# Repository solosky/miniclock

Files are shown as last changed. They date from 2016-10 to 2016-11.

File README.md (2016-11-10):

# MINI CLOCK - 一个小巧漂亮的点阵时钟

标签（空格分隔）： 未分类

---

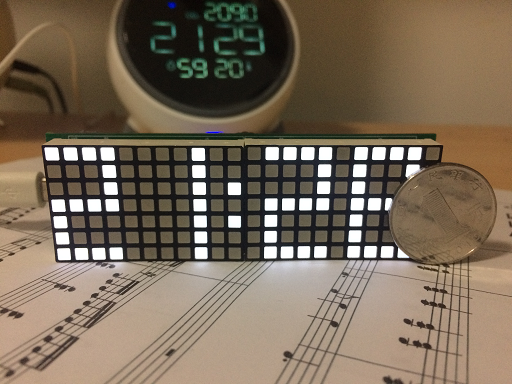
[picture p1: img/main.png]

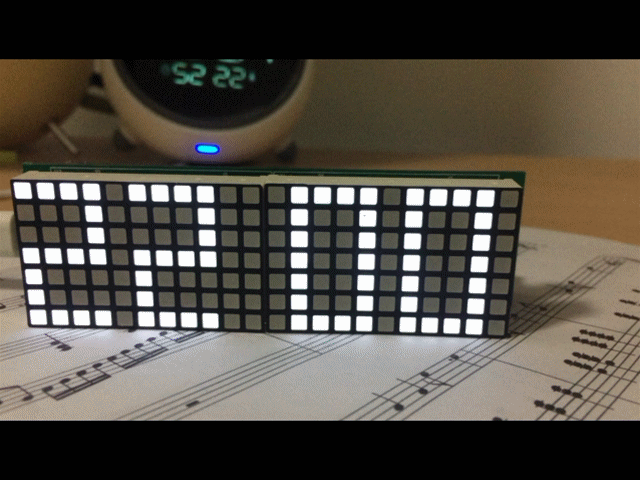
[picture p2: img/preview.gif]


# 特色

 1. 显示时间，日期，温度，湿度
 2. 时钟使用DS3231芯片，精度可以达一年误差30秒，无需校准
 3. 掉电仍走时，再次插电无需重新设置
 4. 支持DHT11/DHT22系列温湿度传感器，温度最高精度0.5℃
 5. 背光自动调节
 6. 支持两种经典字体
 7. 毫无特色的闹钟功能（待实现）
 8. MicroUSB电源接口，可以插USB提供电源
 9. 基于arduino，开放源代码，可以个性化定制

# 更新说明
 v1.1
 
 - 增加亮度调节功能，解决光敏电阻误差大的问题
 
v1.0

 - 第一个版本发布

# 缘起

之前我家的液晶时钟坏了，一直想自己做一个时钟。<br>
在论坛里面搜了很多自制的时钟，要么都是非常简单各种洞洞板各种飞线，要么就不实用的比如12864的点阵液晶时钟，要么就是没有湿度检测的功能。特别是这个湿度检测，相当实用。在北方居住的同学应该知道湿度很干的，需要开加湿器加湿。需要一个东西能显示湿度。<br>
于是参考了很多时钟方案，在X宝选了很久的点阵，终于决定采用白色的7x11的两块点阵来显示时间，显示效果最好。<br>

# 方案

MCU基于Arduino方案，ATmega328p + CH340。这方案很经典，可以一直复用，并且可以使用arduino生态体系里面的库。<br>
时钟芯片必须采用DS3231，精度高，使用简单。<br>
本来想弄一个精度比较高的温湿度传感器芯片，却发现市面上的比较流行只有DHT系列，而且这个精度嘛，实在是太差了，但是也没啥更好的既能检测温度，又能检测湿度的方案了。DHT11精度±1℃，DHT22精度0.5℃，
有钱的同学可以使用DHT22，精度要高点。<br>
显示芯片采用了TM1640，自带行扫瞄。由于买的点阵商家只有共阳级的点阵，选芯片倒是麻烦了点。天微的共阴的显示芯片支持7x11的倒是挺多的，但是共阳支持7x11的芯片实在是太少了，<br> 幸好有一个TM1640，这货支持8x16共阳或者16x8共阴。用来显示8x8的点阵其实刚好，用在这里略微有点浪费。<br>

# BOM单

 - ATMEGA328p LQFP32（主MCU芯片） x1
 - CH340G （串口转USB编程芯片，如不改固件可不焊接） x1
 - DS3231N （高精度时钟芯片） x1
 - TM1640 （LED显示芯片） x2
 - 7x11共阳白色点阵 （[可以点这里购买，淘宝独一家](https://item.taobao.com/item.htm?spm=a1z09.2.0.0.Sjd4vl&id=528278915669&_u=r3umvhn4d2c)） x2
 - MicroUSB座子 x1
 - 贴片微动开关 x4
 - 0805 贴片LED （黄绿色，电源指示灯） x1
 - 0805 0.1uF 贴片电容 若干
 - 0805 22pF 贴片电容 x4
 - 3528 100uF 钽电容 x3
 - 0805 1K 贴片电阻 x若干
 - 0805 10K 贴片电阻 x若干
 - 0805 1M 贴片电阻 x1
 - 0805 100mA 自恢复熔丝 x1
 - 12MHz 49S贴片晶振 x1
 - 16MHz 49S贴片晶振 x1
 - DHT11/DHT22 （温湿度芯片）x1
 - 有源蜂鸣器 x1
 - CR1220电池座 x1
 - CR1220电池 x1
 - 光敏电阻 x1
 - 2.54mm间距的军品孔 （便于拆芯片，可选） x3

相关BOM都是常用的物料，请自行某宝购买即可，但是LED点阵只此一家，手快有，手慢无。

# 说明书

### 普通显示模式

 - 显示时间 10秒钟
 - 显示日期 1秒钟
 - 显示湿度 1秒钟
 - 显示温度 1秒钟

在普通模式下，可以短按K1快速切换下一个显示内容。

### 设置模式

 - 长按K2直到时钟闪烁，进入设置模式
 - 短按K2可以切换设置项，按K1设置项加1，按K3设置项减1
 - 当前的设置项会以0.5秒闪烁
 - 设置项的顺序为，小时 -> 分钟 -> 月 -> 日 -> 年 -> 字体 -> 亮度
 - 设置完字体后，短按K2可以退出设置模式
 - 在设置的过程中，可以随时长按K2退出设置模式；

# 焊接提醒

特别提醒：由于全是贴片原件，请焊接新手先联系一段时间的贴片焊接再组装这个电路板。

 - 建议焊接一个芯片就检查功能是否正常。
 - MicroUSB座子特别不好焊接（主要是焊盘太小了，本来想加长焊盘的，可是发现板子太小，实在是没有空间了），建议的焊接方式是，用蹄型烙铁，蘸松香，挂很少的锡，轻轻的接触下MicroUSB内部的连接点即可。焊接完了用万用表检查是否有短路，如果没有短路再焊接下一个芯片；
 - DHT11和LED点阵均使用军品孔连接，这个主要是为了测试方便  取下来，如果没有也可以直接焊接元件，前提是对自己焊工很自信才行（不然如果没有风枪的话，拆下来巨麻烦）
 - 蜂鸣器和电池座注意焊接的方向

# 刷固件相关软件下载

http://pan.baidu.com/s/1dELJjPn

# 如何刷第一个固件

首先需要焊接好ISP座子，然后你需要一个ATMEL的USBISP编程器，如下图（如果没有可以求助马云家的）。

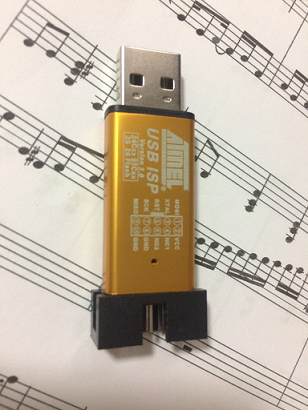
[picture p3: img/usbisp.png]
<br>
1. 按照下图用杜邦线连接 时钟和编程器。<br>
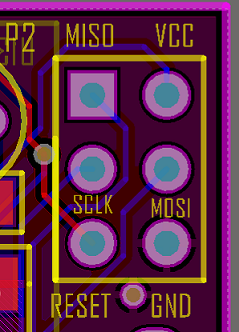
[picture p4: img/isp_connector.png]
<br>
2. 下载 Prog ISP编程软件，运行主程序。<br>
3. 点击RD，如果下面提示框中提示“读出ID成功”，则表示线连接正确，可以写入固件。<br>
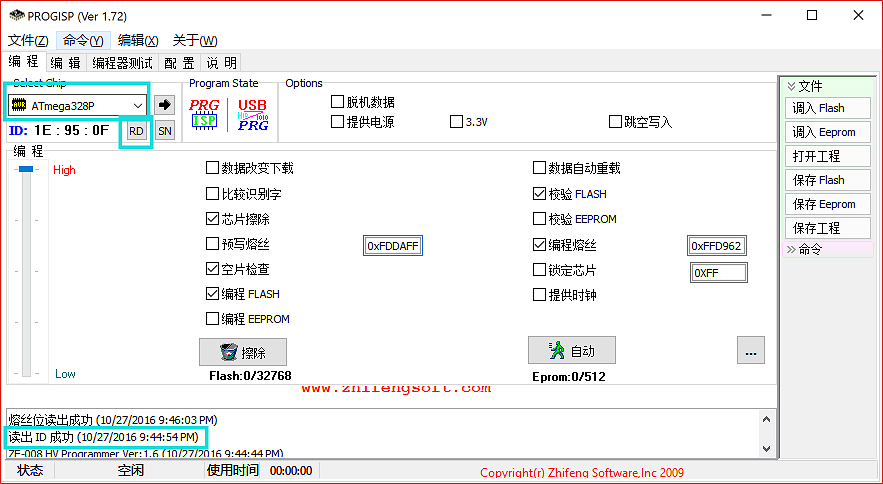
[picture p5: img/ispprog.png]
<br>
4. 点击熔丝位设置，分别设置如下值，然后点击写入熔丝设置。<br>
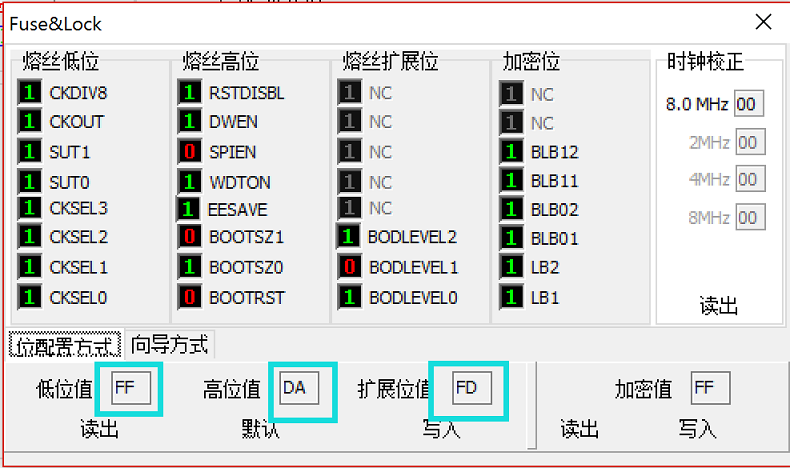
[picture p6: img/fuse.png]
<br>
```
low_fuses=0xFF
high_fuses=0xDA
extended_fuses=0xFD
```
5. 下载最新版本固件（git目录中为build/miniclock-full-firmware-1.0.hex），然后点击文件/调入Flash，选择最新版的固件，点击打开。<br>
6. 点击菜单，命令/写入Flash，稍等片刻即可刷入最新固件。<br>

一些提示：

 - build文件夹有个miniclock-beep-with-bootloader.hex，可以首先刷入这个固件来测试，如果写入成功，蜂鸣器会以间隔一秒的时间蜂鸣；
 - 如果写入提示成功，但是硬件没有反应，建议在刷机软件中点击擦除按钮后重新刷入固件再试。

# 给想改固件的童鞋说明FD

### 如果要改固件，有几个前提：

1. 你需要按照上面初次刷固件的说明，成功的刷入完整的固件，或者测试固件miniclock-beep-with-bootloader.hex。
2. 焊接好CH340G和周边电路。
3. 安装好CH340G驱动。
4. 插上MicroUSB后，打开设备管理器，Ports(COM /LPT)节点下能出现一个USB-Serial CH340G的串口。
5. 短接CH340G的TX和RX端，能通过串口测试。

### 如果上面条件都满足了，并且你有足够的C语言基础，那么大胆的去改固件吧。

虽然这个固件是基于arduino的设计的，由于官方的arduino的开发软件太难用（我感觉是我用过的最难用的IDE），这里强烈推荐另外一个替代软件，PlatformIO。

1. 首先从官网下载PlatformIO，官网在此  http://platformio.org/。
2. 使用git或者github下载全部的源码。
3. 打开platformIO，菜单选择 File / Open Folder，选择源码中的fw目录。
4. 菜单选择 PlatformIO / Initialize or Update PlatformIO Project..
5. Board选择Arduino Uno，点击Process初始化项目。

这一步可能比较慢，需要下载avr系列toolchain，如果有翻墙的工具建议设置下PlatformIO的代理。<br>
设置代理的方式比较简单，在atom用户目录下，新建.apmrc文件，里面写入如下内容（注意改成你的代理IP），保存重开即可。<br>

```text
http-proxy=http://127.0.0.1:1080
https-proxy=http://127.0.0.1:1080
strict-ssl=false
```
### atom用户目录
windows下为 C:\Users\{登录用户}\.atom<br>
linux或者mac为 ~/.atom<br>

上面的步骤都完了之后，点击菜单 PlatformIO / Build之后IDE就会自动构建，成功后构建窗口有提示。
点击菜单 Platform / Upload，IDE就会自动上传固件到时钟里面并运行。<br>
自此，请发挥你的想象里，随意的改固件吧！<br>
如果会用git的话，欢迎pull request!!<br>

# 呃，外壳问题。。。
好吧，既然你问到了，那我就说下。<br>
原计划是准备做个外壳的，用白底透光的亚克力做面板，显示效果会上一个档次（参见小米体重秤，这个时钟的灵感就是来自这个）。<br>
但是，但是。。我不会做3d设计啊。。<br>
而且纯PCB放在桌上，很酷，不是吗<br>
还有个比较严重的问题，，我没有留固定孔。。<br>
不是我不留啊，是因为这个板子太小了，实在是没空间了哇。。喂，有话好好说嘛~<br>
好吧，既然你们强烈要求，我可能有时间就搞个外壳，只是可能啊。因为学新东西太花时间了，而且我要上班啊，摔~ <br>

# 看到这里，说明你对这个项目真的很感兴趣，是吧
欢迎大神们小白们加QQ群 `320437972`一起玩硬件吧。<br>
我是软件工程师，硬件就是小白，哈哈。<br>
下一个项目计划中，准备玩玩远程采集图片，温湿度信息，不过会采用STM32方案。一样的，会全部开源。<br>

# 最后一点，真的是最后一点了，版权说明
本时钟是基于apache Lisence 2.0 开源协议发布，允许商业使用或修改包括源代码和PCB，而无需经过我的授权。<br>
但是请保留署名作者的权利。<br>
如果在商业使用了本时钟的任何源代码和PCB内容，恕不提供技术支持，抱歉。<br>
但如果能告知我使用了我的设计，我会感到很高兴的。<br>

solosky 作品，于2016年秋

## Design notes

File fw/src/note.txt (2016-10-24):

fuse:
nano.menu.cpu.atmega328.bootloader.low_fuses=0xFF
nano.menu.cpu.atmega328.bootloader.high_fuses=0xDA
nano.menu.cpu.atmega328.bootloader.extended_fuses=0x05

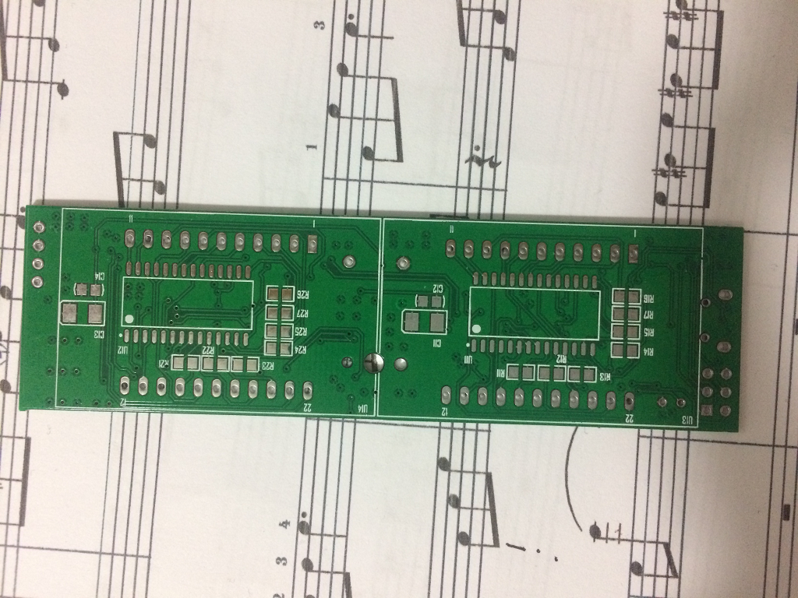
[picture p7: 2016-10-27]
img/pcb_bottom.png

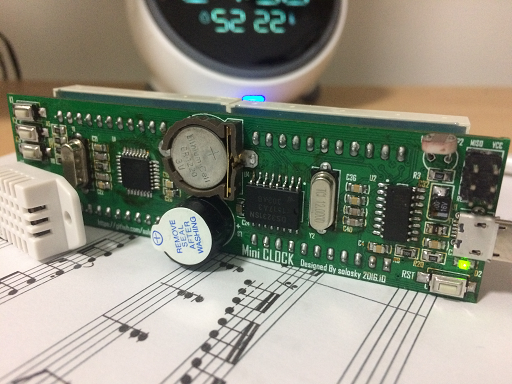
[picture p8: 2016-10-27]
img/back.png

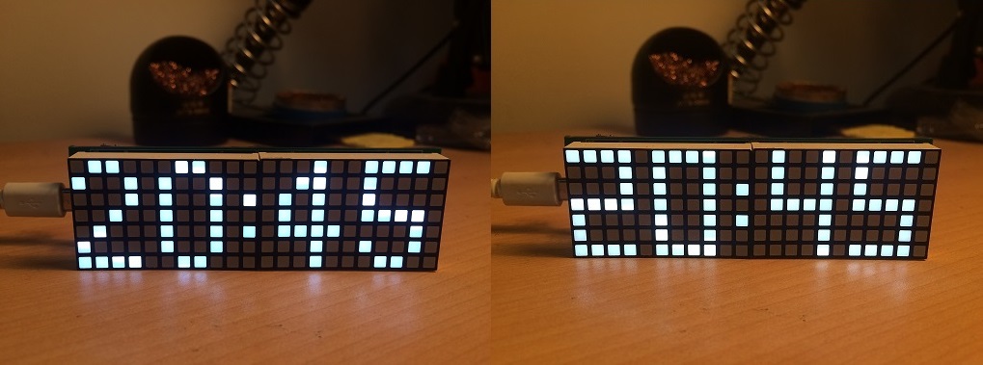
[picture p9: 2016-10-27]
img/2fonts.jpg

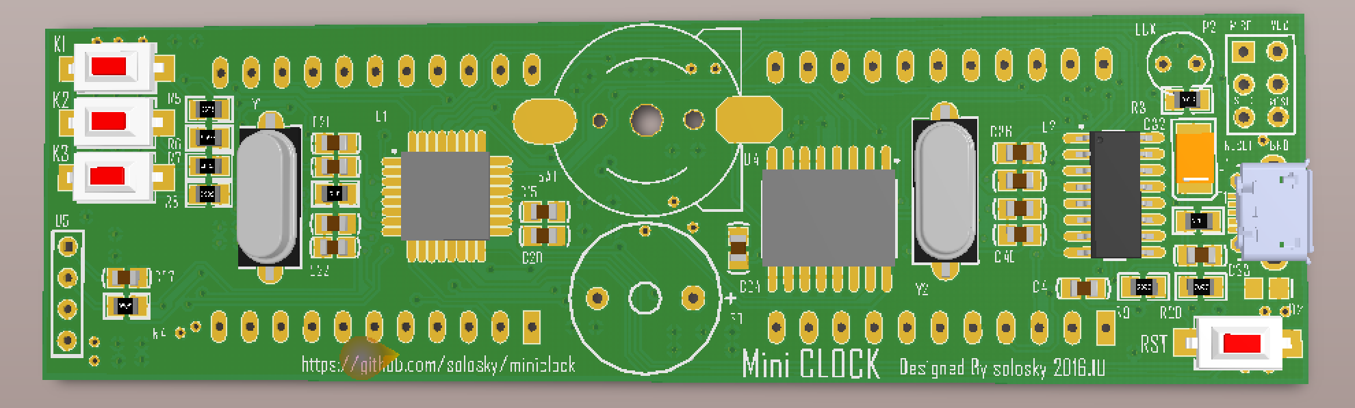
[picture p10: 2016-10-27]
img/ad_pcb.png

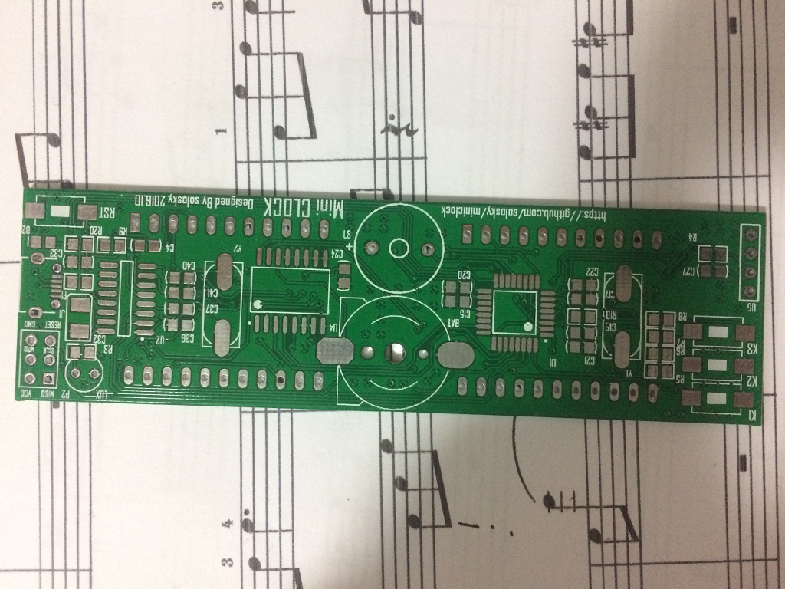
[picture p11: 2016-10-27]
img/pcb_top.png

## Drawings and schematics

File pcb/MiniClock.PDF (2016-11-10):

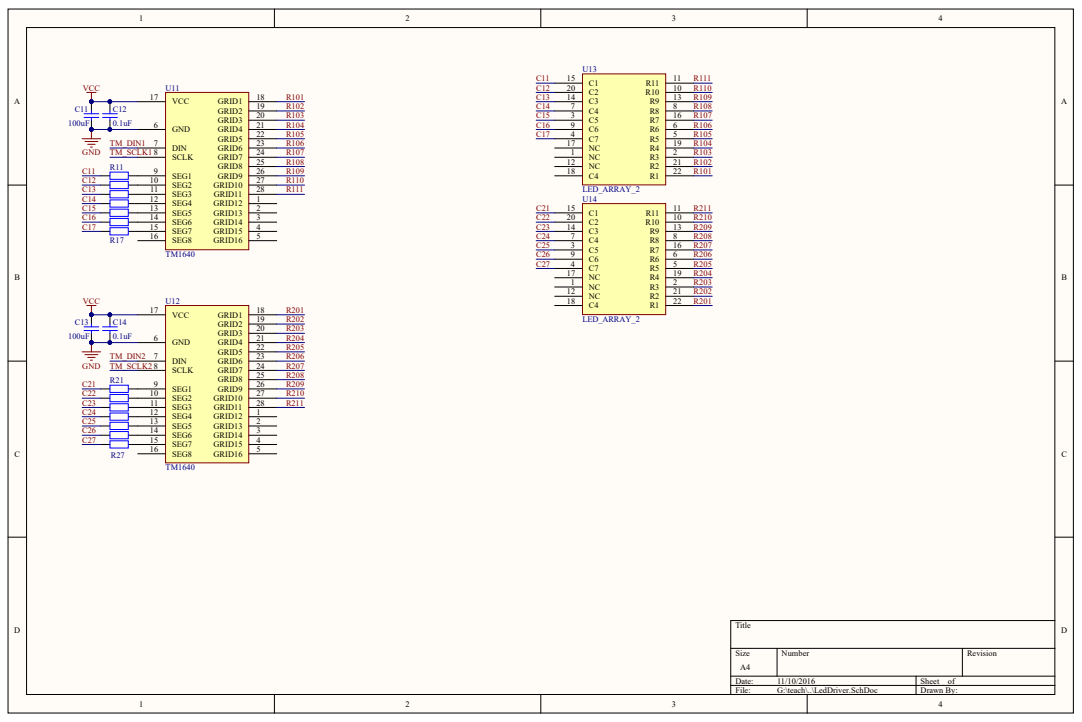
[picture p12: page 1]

SEG6 14 | 3
SEG7 15 | 4

SEG5 13 | 2

Size A4 | Number | Revision

Date: 11/10/2016 | Sheet of
File: G:\teach\..\LedDriver.SchDoc | Drawn By:

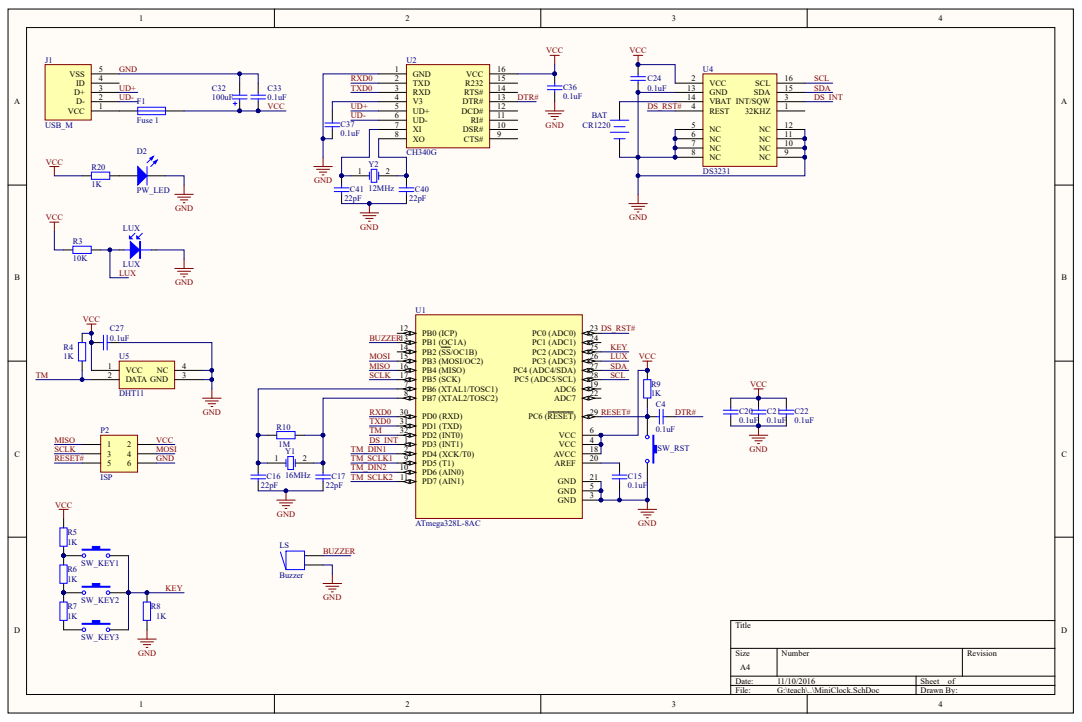
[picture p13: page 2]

Date: 11/10/2016 | Sheet of
File: G:\teach\..\MiniClock.SchDoc | Drawn By:

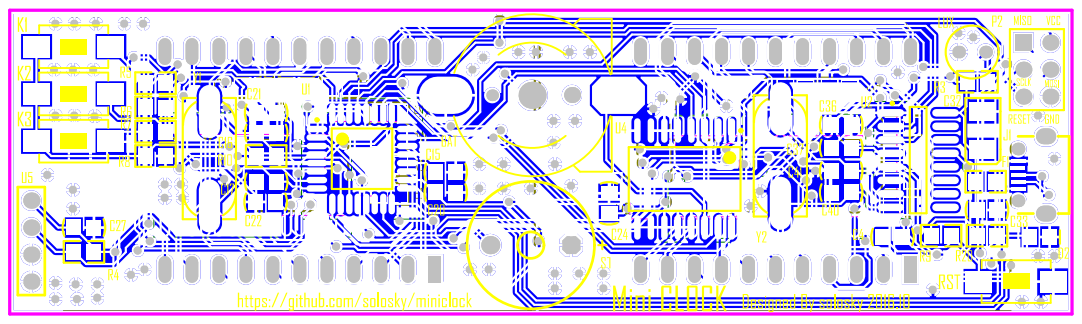
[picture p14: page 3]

Comment | Description | Designator | Footprint | LibRef | Quantity
CR1220 | Multicell Battery | BAT | CR1220 | Battery | 1
Cap | Capacitor | C4, C12, C14, C15, C16, C17, C20, C21, C22, C24, C27, C33, C36, C37, C40, | C-0805 | Cap | 16
Cap | Capacitor | C11, C13 | CAP-3528 | Cap | 2
Cap Pol2 | Polarized Capacitor (Axial) | C32 | CAP-3528 | Cap Pol2 | 1
PW_LED | Typical RED, GREEN, YELLOW, AMBER GaAs LED | D2 | LED-0805 | LED2 | 1
Fuse 1 | Fuse | F1 | 0805-1 | Fuse 1 | 1
USB_M | Micro/Mini USB | J1 | USB_MICRO_5S_B | USB_M | 1
Buzzer | Magnetic Transducer Buzzer | LS | BEEP-S | Buzzer | 1
LUX | | LUX | AX_2.54 | LUX | 1
ISP | Header, 3-Pin, Dual row | P2 | HDR2X3 | Header 3X2 | 1
Res2 | Resistor | R3, R4, R5, R6, R7, R8, R9, R10, R11, R12, R13, R14, R15, R16, R17, R20, R21, R22, R23, R24, R25, R26, R27 | 0805-1 | Res2 | 23
SW-PB | Switch | SW_KEY1, SW_KEY2, SW_KEY3, SW_RST | SW_PB2_A1 | SW-PB | 4
ATmega328L-8AC | 8-Bit AVR Microcontroller with 8K Bytes of In-System Programmable Flash Memory | U1 | 32A_M | ATmega8L-8AC | 1
CH340G | | U2 | SOIC-16 | CH340G | 1
DS3231 | | U4 | SOIC-16W | DS3231 | 1
DHT11 | | U5 | DHTxx_simple | DHT22 | 1
TM1640 | 段 位 驱动芯片 8 ×16 LED | U11, U12 | SOIC28W | TM1640 | 2
LED_ARRAY_2 | | U13, U14 | DIP22_LEDARR | LED_ARRAY_2 | 2
16MHz | Crystal Oscillator | Y1 | X-SM49 | XTAL | 1
12MHz | Crystal Oscillator | Y2 | X-SM49 | XTAL | 1

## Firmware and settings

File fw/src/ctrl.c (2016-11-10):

#include "ctrl.h"
#include "debug.h"
#include "timers.h"

ctrl_t _ctrl0;


ctrl_t* ctrl_default(){
        return &_ctrl0;
}


void ctrl_init(ctrl_t* ctrl){

        // debug init
        usart_init(usart_default(), DBG_USART_BAUD);
        debug_init(usart_default());

        //device i2c_init
        fb_init(fb_default());
        i2c_init(i2c_default());
        rtc_init(rtc_default(), i2c_default());
        dht_init(dht_default());
        view_init(view_default(), fb_default());

        key_init(key_default(), _ctrl_callback_on_key);
        lux_init(lux_default(), _ctrl_callback_on_lux);

        //read rtc and read setting
        view_data_t* view_data = &(view_default()->view_data);
        rtc_read(rtc_default(), &(view_data->rtc_date_time));
        setting_read(&view_data->setting_data);
        printf("ft:%d\n", view_data->setting_data.font_type);

        // create and start timers
        _ctrl_init_timers(ctrl);

        // it's show time!!!!
        view_show_chain(view_default(), _view_chain_default);

}

void _ctrl_init_timers(ctrl_t* ctrl){
        timer_new("key_scan", KEY_SCAN_PEROD_MS / portTICK_PERIOD_MS, _ctrl_timer_key_scan, true);
        timer_new("view_tick", VIEW_TICK_PEROD_MS / portTICK_PERIOD_MS, _ctrl_timer_view_tick, true);
        timer_new("read_lux", 150 / portTICK_PERIOD_MS,  _ctrl_timer_read_lux, true);
        timer_new("read_dht", 1000 / portTICK_PERIOD_MS, _ctrl_timer_read_dht, true);
        timer_new("read_rtc", 1000 / portTICK_PERIOD_MS, _ctrl_timer_read_rtc, true);
}

////////////////////////////////////////////////////////////////////////////////
void _ctrl_timer_key_scan(void* p){
        key_scan(key_default());
}

void _ctrl_timer_read_lux(void* p){
        lux_sample(lux_default());
}

void _ctrl_timer_read_rtc(void* p){
        view_data_t* view_data = &(view_default()->view_data);
        rtc_date_time_t* dt = &(view_data->rtc_date_time);
        if(view_data->ctrl_mode == CM_NORMAL) {
                result_t ret = rtc_read(rtc_default(), dt);
                //printf("h24:%d, pm=%d, h=%d\n", dt->h24, dt->pm, dt->hour);
                if(ret != ERR_OK) {
                        printf("read rtc error:%d\n", ret);
                        return;
                }
        }
}

void _ctrl_timer_view_tick(void* p){
        view_frame_tick(view_default());
}

void _ctrl_timer_read_dht(void* p){
        dht_data_t* dht_data = &(view_default()->view_data.dht_data);
        result_t ret = dht_read(dht_default(), dht_data);
        if(ret != ERR_OK) {
                printf("dht read error:%d\n", ret);
        }
        //printf("dht: %d %d\n", dht_data->humidity, dht_data->temperature);
}

void _ctrl_switch_mode(ctrl_t* ctrl, uint8_t ctrl_mode){
        printf("switch:%d\n", ctrl_mode);
        view_t* view = view_default();
        view_data_t* view_data = &(view->view_data);
        if(ctrl_mode != view_data->ctrl_mode) {
                view_data->ctrl_mode = ctrl_mode;
                if(ctrl_mode == CM_NORMAL) {
                        //TODO save setting
                        view_show_chain(view, _view_chain_default);
                }else{
                        view_data->set_field = SF_HOUR;
                        view_show_page(view,PG_TIME_SET);
                }
        }

}

////////////////////////////////////////////////////////////////////////////////

void _ctrl_callback_on_key(uint8_t key, uint8_t event){
        printf("key:%d,%d\n",key, event);
        view_t* view = view_default();
        ctrl_t* ctrl = ctrl_default();
        view_data_t * view_data = &(view_default()->view_data);
        if(key == KEY_2) {
                if( event == KEY_EVENT_KEYDOWN_LONG) {
                        //enter or leave setting mode
                        if(view_data->ctrl_mode == CM_NORMAL) {
                                _ctrl_switch_mode(ctrl, CM_SETTING);
                        }else{
                                _ctrl_switch_mode(ctrl, CM_NORMAL);
                        }
                }else if(event == KEY_EVENT_KEYDOWN) {
                        //enter setting mode
                        if(view_data->ctrl_mode == CM_SETTING) {
                                //next set field
                                if(view_data->set_field == SF_LUX) {
                                        //exit set mode
                                        _ctrl_switch_mode(ctrl, CM_NORMAL);
                                }else{
                                        //switch to next field
                                        view_data->set_field++;
                                        if(view_data->set_field == SF_MONTH) {
                                                view_show_page(view, PG_DATE_SET);
                                        }else if(view_data->set_field == SF_YEAR) {
                                                view_show_page(view, PG_YEAR_SET);
                                        }else if(view_data->set_field == SF_FONT) {
                                                view_show_page(view, PG_FONT_SET);
                                        }else if(view_data->set_field == SF_LUX){
                                                view_show_page(view, PG_LUX_SET);
                                        }
                                }
                        }
                }

        }


        if(key == KEY_1 && event == KEY_EVENT_KEYDOWN) {
                if(view_data->ctrl_mode == CM_SETTING) {
                        _ctrl_adjust_field_value(ctrl_default(), INCR);
                        _ctrl_apply_setting_value(ctrl_default());
                }else{
                      view_flip_next(view_default());
                }
        }

        if(key == KEY_3 && event == KEY_EVENT_KEYDOWN) {
                if(view_data->ctrl_mode == CM_SETTING) {
                        _ctrl_adjust_field_value(ctrl_default(), DECR);
                        _ctrl_apply_setting_value(ctrl_default());
                }
        }
}

void _ctrl_callback_on_lux(uint16_t lux){
        printf("lux: %d\n",lux);
        fb_t* fb = fb_default();
        setting_data_t* st = &(view_default()->view_data.setting_data);
        lux -= st->lux_adj * 50;
        if(lux < 100) {
                fb_set_brightness(fb, 7);
        }else if(lux < 150) {
                fb_set_brightness(fb, 6);
        }else if(lux < 200) {
                fb_set_brightness(fb, 5);
        }else if(lux < 250) {
                fb_set_brightness(fb, 4);
        }else if(lux < 300) {
                fb_set_brightness(fb, 3);
        }else if(lux < 350) {
                fb_set_brightness(fb, 2);
        }else if(lux < 400) {
                fb_set_brightness(fb, 1);
        }else{
                fb_set_brightness(fb, 0);
        }
}

// magic, haha
#define ADD_DELTA(ob, f, min, max, delta) {if(ob->f + delta == max + 1) {ob->f = min; }else if(ob->f + delta == min) {ob->f = max; }else{ ob->f+=delta; }}
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

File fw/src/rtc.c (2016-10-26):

#include "rtc.h"
#include "i2c.h"
#include "debug.h"

rtc_t _rtc0;

rtc_t* rtc_default(){
  return &_rtc0;
}

void rtc_init(rtc_t* rtc, i2c_t* i2c){
        rtc->rtc_addr = RTC_ADDR;
        rtc->i2c = i2c;

        //1Hz pin enable pull up TODO ..
        pinMode(RTC_INT_PIN, INPUT_PULLUP);
        EICRA = _BV(ISC11) | _BV(ISC10);
        EIMSK = _BV(INT1);


        //init control register
        _rtc_write_regiter(rtc, 0xE, 0);  // 1Hz SqWave, disable all alarms
        _rtc_write_regiter(rtc, 0xF, 0);  // disable 32KHz output

        rtc_date_time_t rtc_date_time;
        rtc_read(rtc, &rtc_date_time);
        _rtc_sync_rtc_time(rtc, &rtc_date_time);
}

result_t rtc_read(rtc_t* rtc, rtc_date_time_t* rtc_date_time){
        result_t ret;
        byte_t buff[7];

        ret = _rtc_read_regiter(rtc, 0, buff, sizeof(buff));
        if(ret != ERR_OK) {
                return ret;
        }

        // parse rtc info
        rtc_date_time->second = _rtc_bcd2dec(buff[0]);   //second
        rtc_date_time->minute = _rtc_bcd2dec(buff[1]);   //minute
        rtc_date_time->h24    = (buff[2] >> 6) == 0;
        if(rtc_date_time->h24) {
                rtc_date_time->hour = _rtc_bcd2dec(buff[2] & 0x3F);
        }else{
                rtc_date_time->pm   = (buff[2] & _BV(5)) > 0;
                rtc_date_time->hour = _rtc_bcd2dec(buff[2] & 0x1F); //hour
        }
        rtc_date_time->week = _rtc_bcd2dec(buff[3]);
        rtc_date_time->day = _rtc_bcd2dec(buff[4]);
        rtc_date_time->month = _rtc_bcd2dec(buff[5] & 0x1F);
        rtc_date_time->year = _rtc_bcd2dec(buff[6]);

        return ERR_OK;
}


result_t rtc_write(rtc_t* rtc, rtc_date_time_t* rtc_date_time){
        result_t ret;
        byte_t buff[8];

        buff[0] = 0;  // first reg address bytes

        buff[1] = _rtc_dec2bcd(rtc_date_time->second);
        buff[2] = _rtc_dec2bcd(rtc_date_time->minute);
        if(rtc_date_time->h24) {
                buff[3] = _rtc_dec2bcd(rtc_date_time->hour);
        }else{
                buff[3] = _rtc_dec2bcd(rtc_date_time->hour);
                buff[3] |= _BV(6);
                if(rtc_date_time->pm) {
                        buff[3] |= _BV(5);
                }
        }
        buff[4] = _rtc_dec2bcd(rtc_date_time->week);
        buff[5] = _rtc_dec2bcd(rtc_date_time->day);
        buff[6] = _rtc_dec2bcd(rtc_date_time->month);
        buff[7] = _rtc_dec2bcd(rtc_date_time->year);

        ret = i2c_write_buff(rtc->i2c, rtc->rtc_addr, buff, sizeof(buff));
        if(ret != ERR_OK) {
                printf("rtc_write data error: %d\n", ret);
                return ret;
        }

        return ERR_OK;
}


///////////////////////////////////////////////////////////////////////////////
// private functions
//////////////////////////////////////////////////////////////////////////////

byte_t _rtc_bcd2dec(byte_t val){
        return ( (val/16*10) + (val%16) );
}


byte_t _rtc_dec2bcd(byte_t val){
        return ( (val/10*16) + (val%10) );
}

void _rtc_sync_rtc_time(rtc_t* rtc, rtc_date_time_t* rtc_date_time){
        rtc_time_t* tm = &(rtc->rtc_time);
        tm->hour = rtc_date_time->hour;
        tm->second = rtc_date_time->second;
        tm->minute = rtc_date_time->minute;
        if(!rtc_date_time->h24 && rtc_date_time->pm) {
                tm->hour += 12;
        }
}


result_t _rtc_read_regiter(rtc_t* rtc, byte_t reg, byte_t* buff, uint8_t size){
        // write address
        result_t ret;
        ret = i2c_write(rtc->i2c, rtc->rtc_addr, reg);
        if(ret != ERR_OK) {
                printf("rtc_read: write reg addr error: %d\n", ret);
                return ret;
        }
        ret = i2c_read_buff(rtc->i2c, rtc->rtc_addr, buff, 7);
        if(ret != ERR_OK) {
                printf("rtc_read: read data error: %d\n", ret);
                return ret;
        }
        return ret;
}


result_t _rtc_write_regiter(rtc_t* rtc, byte_t reg, byte_t value){
        // write address
        result_t ret;
        byte_t buff[2];

        buff[0] = reg;
        buff[1] = value;

        ret = i2c_write_buff(rtc->i2c, rtc->rtc_addr, buff, sizeof(buff));
        if(ret != ERR_OK) {
                printf("rtc_read: write reg addr error: %d\n", ret);
                return ret;
        }
        return ERR_OK;
}

ISR(INT1_vect){
        rtc_time_t* tm = &(_rtc0.rtc_time);
        if(tm->second < 59) {
                tm->second++;
                return;
        }

        tm->second = 0;
        if(tm->minute < 59) {
                tm->minute++;
                return;
        }
        tm->minute = 0;
        if(tm->hour < 23) {
                tm->hour++;
                return;
        }
        tm->hour = 0;
}

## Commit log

2016-10-24 view and timer
2016-11-10 export MiniClock.PDF and add lux setting
    [LedDriver.SchDoc, MiniClock.SchDoc]
